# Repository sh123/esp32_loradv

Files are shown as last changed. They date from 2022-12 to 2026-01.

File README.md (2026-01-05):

# ESP32 Codec2/OPUS DV Handheld Transceiver

## Introduction
⚠ **Please note that this device is experimental and lacks any form of certification. The author holds no responsibility for any fines incurred due to spectrum misuse, legal violations, or damages caused during its use. As with any experimental project, it is essential that you fully understand what you are doing and use it at your own risk.**

This project is a hobby/amateur/toy/educational radio ESP32 based LoRa/FSK Codec2/OPUS DV 3d printed handheld trasceiver a.k.a. walkie-talkie, which is using 1W/2W `E22-400M30S/E22-400M33S` (SX1268) radio module (UHF, 70cm band) or optionally 100mW `RA-01/RA-02` (SX1278) module. 

In theory, it could also be used with other modules from `E22-xxxMxxS` series with compatible pinouts, but targetting other bands, such as `E22-868M30S/E22-900M30S` (SX1262) modules (UHF, 868/915 MHz) or `E22-170M33S`/`E22-220M30S`, but not tested.

It functions like a standard FM walkie-talkie and, for simplicity and traffic optimization, does not utilize any communication protocol. Instead, it transmits audio codec frames (DV) using pre-configured digital radio modulation, such as LoRA or FSK. There are ideas to add voice over AX.25 and perhaps M17 protocol support in the future.

Overall components cost for this project is about 15-20$.

Schematics for the new board design, which includes integrated components, can be found in the `extras/schematics` directory. The pinouts remain compatible with the first prototype version. While there is a designated space for a GPS module, it should not be soldered as it is not currently supported; it is included solely for potential future experiments.

First prototype is based on https://github.com/sh123/esp32_loraprs modem, but uses additional peripherals:
- I2S speaker module MAX98357A + 4-8ohm 3w speaker (40mm diameter)
- I2S microphone INMP441
- PTT button (new board uses right angeled push button)
- Rotary encoder with push button (new board uses EC11 right angeled encoder)
- Small OLED display SSD1306 128x32
- Battery voltage monitoring (just voltage divider fed into ADC pin, see schematics)
- Powered from a single commonly avaialble 18650 cell (for example from old laptop battery)
- Uses combined charge + 5v boost controller based on Hotchip HT4928S (it is usually used in low capacity single cell USB power banks), but **better to use controllers such as IP5305_SK or similar without auto shutdown on low current!**.

Supports next features:
- Supports LoRa and FSK (no FEC) modulation with configurable modulation parameters from settings
- Supports Codec2 (low bit rate, 700-3200 bps) and OPUS (medium/high bit rate, 2400-512000 bps) audio codecs, codec could be selected from settings
- Goes into ESP32 light sleep when no activity, so all power consumption is around 30-40mA when in sleep RX (even lower with built-in esp32 leds scrapped), wakes up on new data from radio module or when user starts transmitting, consumes about 90-100mA in active receive and about 700-800mA in full power 1W transmit, so single 18650 cell should last for about 48 hours when in idle RX
- Settings menu on long encoder button click, allows to change frequency and other parameters
- Output power tunable from settings from ~1mW (for ISM toy usage) up to 2W (for amateur radio experiments)
- Experimental no warranty privacy option for ISM low power usage (⚠ **check your country regulations if it is allowed by the ISM band plan before experimenting as it might be illegal in some countries**), it is based on [ChaCha20-Poly1305](https://en.wikipedia.org/wiki/ChaCha20-Poly1305) stream cypher provided by [rwheater/Crypto](https://github.com/rweather/arduinolibs) library, it is comparable to AES256, uses 256 bits key, provides message authentication, but should have lower CPU requirements and power usage.

Planned features/ideas:
- Frequency split repeater mode, where two transceivers will be linked using espnow, so one will receive voice on RX frequency and then send packet using espnow to second transmitter which will receive packet using espnow and re-transmit it on TX frequency, this way receiver and transmitter could be positioned further apart with separate antennas thus eliminating need for duplexer
- Bluetooth headset pairing to use with hands free, so can use headset instead of i2s speaker/mic when needed
- Voice over AX.25, so meta data such as callsign could be included and visible on the other end
- M17 protocol support

## Build instructions
- Modify `include/config.h` if needed
- Install platformio
- Build with platformio
- Upload with platformio

## BOM
Bill of materials (BOM) for the new board constuction (credits to n0p and his club members for collecting it)
```
ESP-WROOM32 30pin - https://es.aliexpress.com/item/1005005953505528.html
Modem LoRa E22-400M30S (SX1268) - https://es.aliexpress.com/item/1005003122961059.html
I2S speaker module MAX98357A - https://es.aliexpress.com/item/1005005383121121.html
4ohm 3w speaker (40mm diameter) - https://es.aliexpress.com/item/1005006684947554.html
I2S microphone INMP441 - https://es.aliexpress.com/item/1005007889064664.html
Rotary encoder with push button - https://es.aliexpress.com/item/1005008091948369.html 
Small OLED display SSD1306 128×32 - https://es.aliexpress.com/item/1005008096924594.html
Uses combined charge + 5v boost controller - https://es.aliexpress.com/item/1005008657948784.html

18650 Cell
Botón switch tactile SKHH angled - https://es.aliexpress.com/item/1005005369415986.html
SMA-J-P-X-ST-EM1 Edgemount - https://es.aliexpress.com/item/10000000835065.html
R1 - 100k 0603 - https://es.aliexpress.com/item/1005005677654015.html
R2-R7 - 10k 0603 - https://es.aliexpress.com/item/1005005677654015.html
C1, C3-C8, C10, C11 - 100nF 0603 - https://es.aliexpress.com/item/32371454429.html
C2 - Elec 100uF SMD 3×5,3 - https://es.aliexpress.com/item/1005006724593986.html
C9 - 47uF Radial D4 mm P2 mm - https://es.aliexpress.com/item/1005005022177024.html

GPS - OPTIONAL - UNSUPPORTED ON WALKIE FW - CONFLICTS WITH ON BOARD SERIAL PORT PROGRAMMER - https://es.aliexpress.com/item/1005008733474270.html
```

## Pictures

Two fully 3d printed prototypes were built based on `esp32_loraprs` modem board.

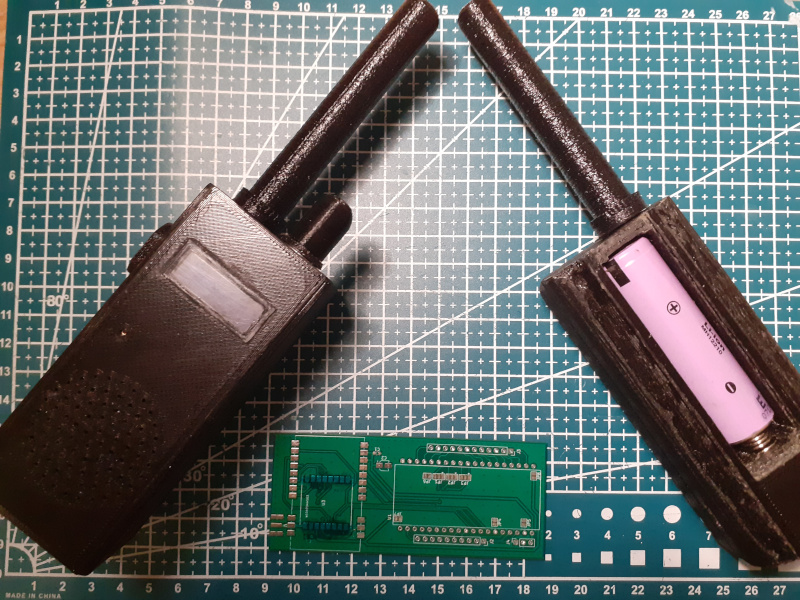
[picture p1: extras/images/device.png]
Device


List of peripherals used.

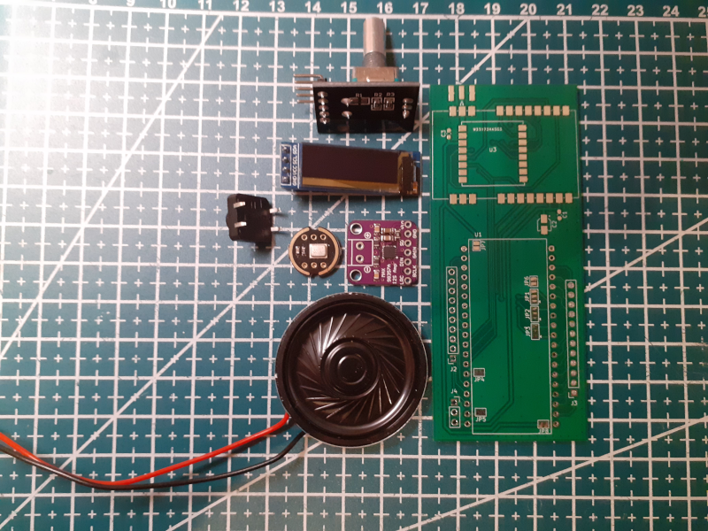
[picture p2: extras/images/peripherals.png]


New board design with all components integrated into the board (except battery and charging circuit).

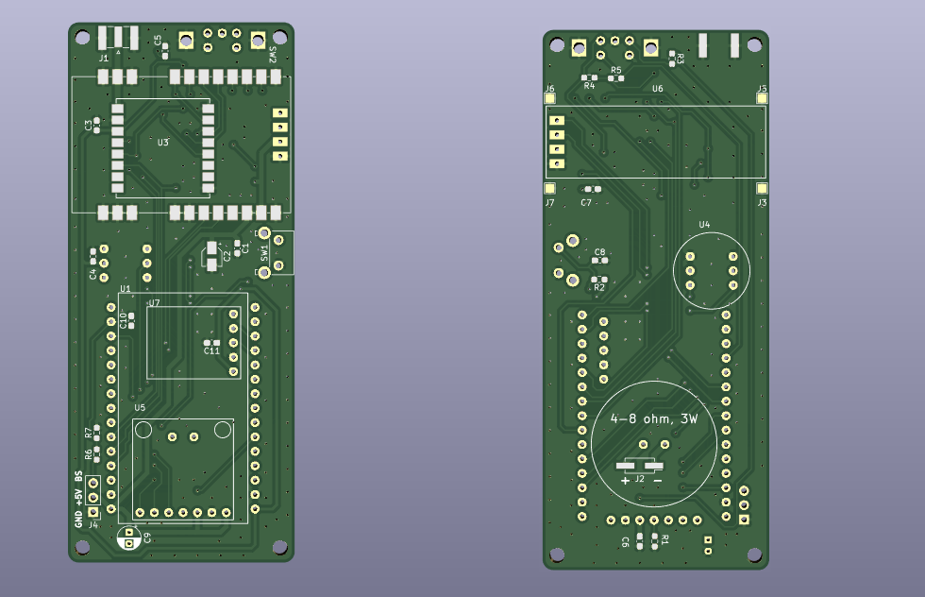
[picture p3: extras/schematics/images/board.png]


Case for the new board version with battery compartment.

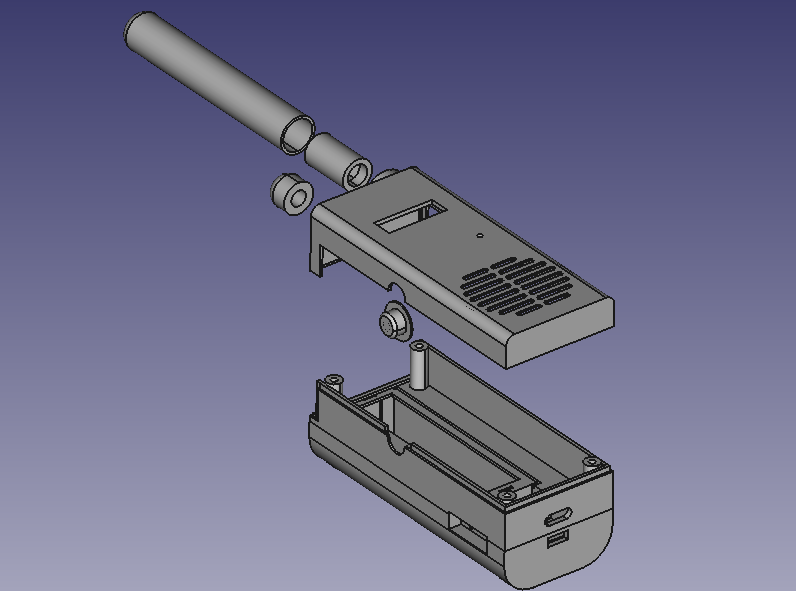
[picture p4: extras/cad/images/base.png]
CAD


Assembled board with new design.

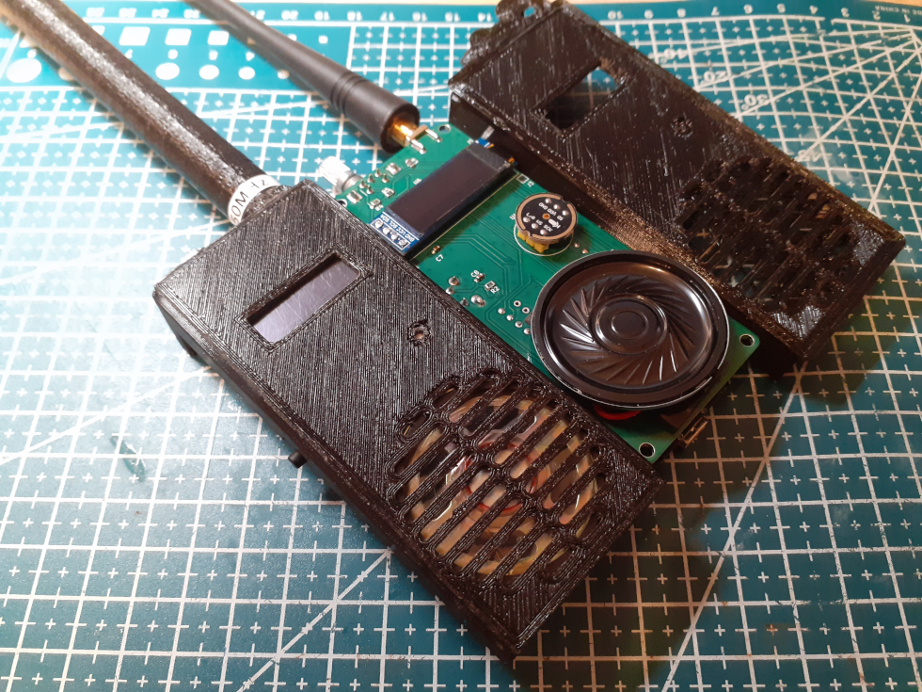
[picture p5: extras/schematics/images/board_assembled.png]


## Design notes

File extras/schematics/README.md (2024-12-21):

# ESP32 DV transceiver board

This is transceiver board for ESP32 DV handheld transceiver with integrated modules, except battery and charge controller.

Board

Board

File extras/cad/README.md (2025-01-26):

# CAD models for the transceiver case
- `antenna_base.*` - antenna foundation, antenna spiral widing is done with 1.3mm copper solid wire on 8mm diameter scaffolding, ~8 turns with 6mm step, with this configuration resonance will be at around 400 MHz, cut with small 2-4mm incriments to move resonance to higher frequency (e.g. to desired 433 or 446 MHz), control resonance after each step with antenna analyzer when antenna cover is attached.
- `antenna_cover_short.*` - antenna cover for 433 MHz (TPU plastic is preferred).
- `base.*` - model for the base part of the case where board is inserted.
- `upper.*` - upper part of the case with 18650 battery compartment and combined charge 5v boost up converter.
- `upper_no_battery.*` - upper part of the case without battery compartment, e.g. when planning to power using ESP32 USB port only.
- `knob.*` - rotary encoder knob (TPU plastic is preferred).
- `ptt.*` - PTT button cover (TPU plastic is preferred).
- `battery_lid.*` - battery compartment lid.

CAD

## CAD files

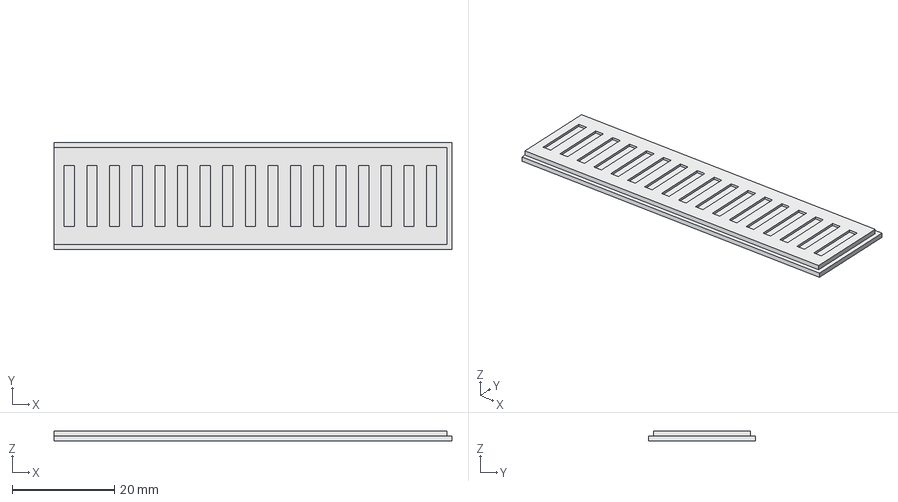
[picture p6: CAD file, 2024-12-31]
extras/cad/battery_lid.FCStd
78.0 x 21.0 x 2.00 mm

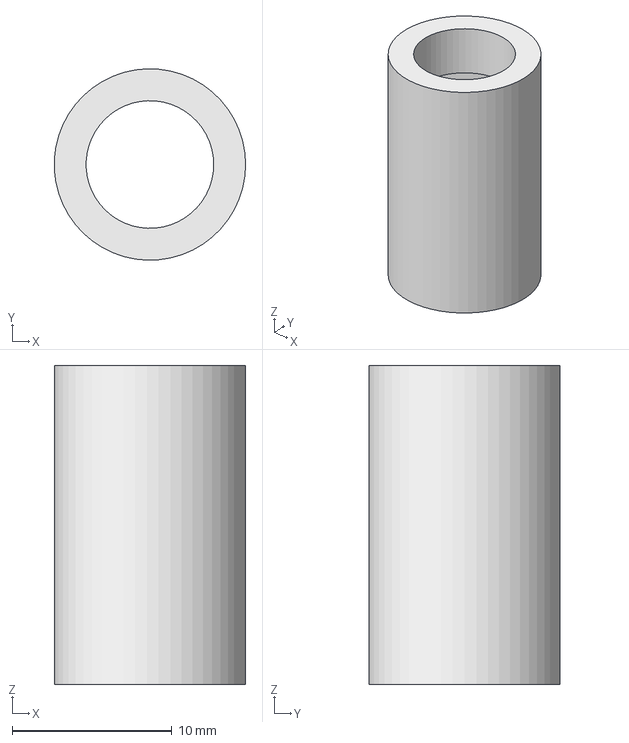
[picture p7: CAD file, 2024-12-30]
extras/cad/antenna_base.FCStd
12.0 x 12.0 x 20.0 mm

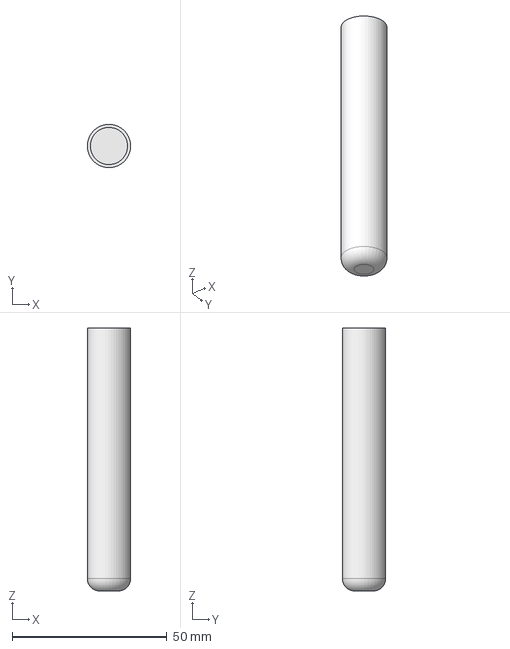
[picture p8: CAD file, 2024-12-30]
extras/cad/antenna_cover_short.FCStd
14.0 x 14.0 x 85.0 mm

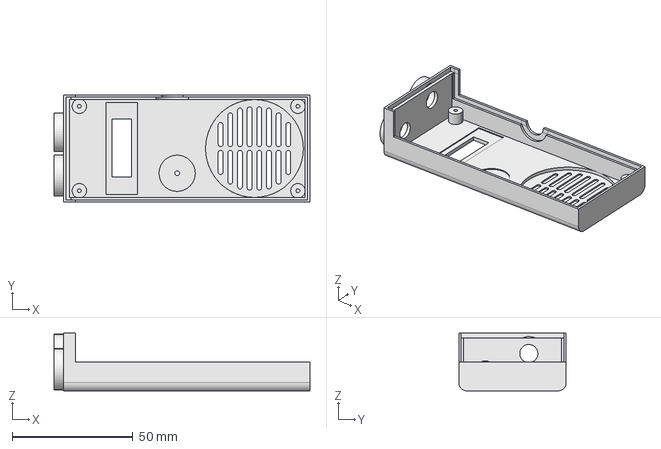
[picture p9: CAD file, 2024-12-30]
extras/cad/base.FCStd
106.0 x 44.5 x 24.0 mm

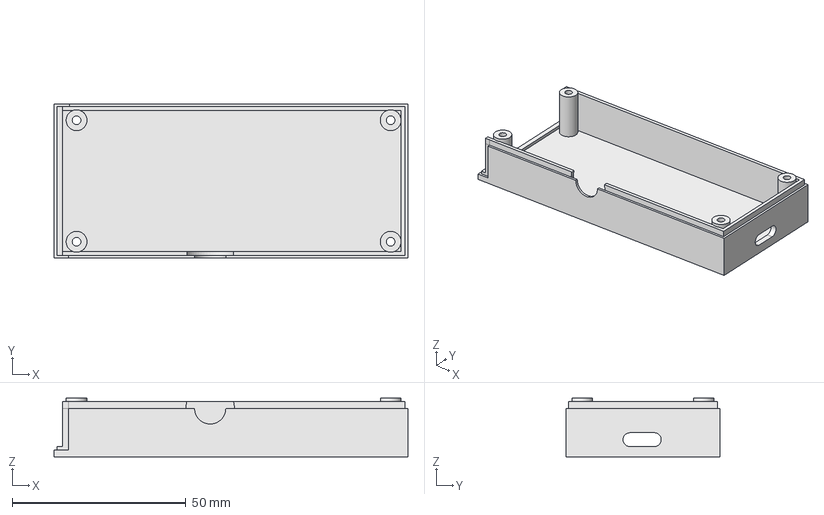
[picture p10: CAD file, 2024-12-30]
extras/cad/upper_no_battery.FCStd
102.0 x 44.5 x 17.0 mm

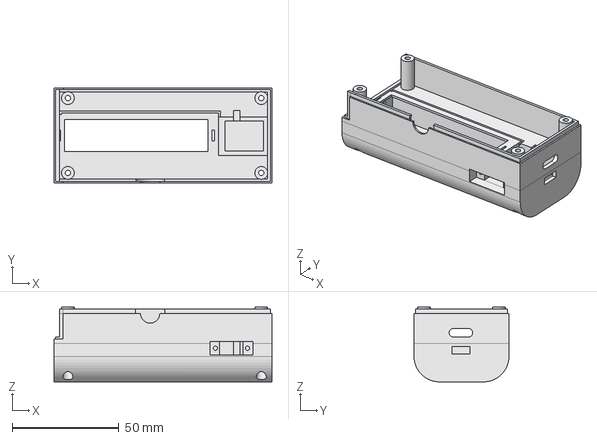
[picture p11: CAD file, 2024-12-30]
extras/cad/upper.FCStd
102.0 x 44.5 x 35.0 mm

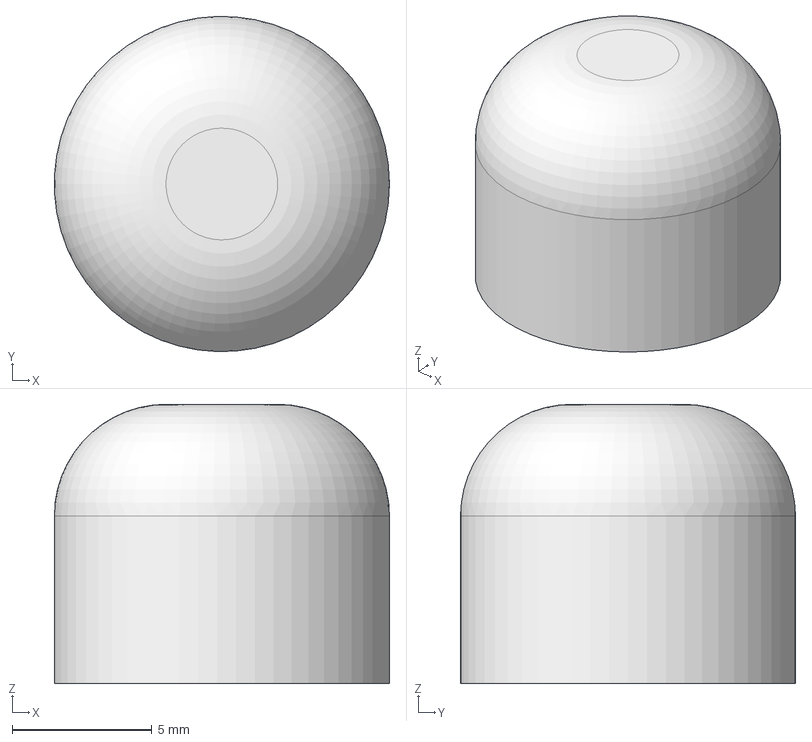
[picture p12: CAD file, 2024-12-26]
extras/cad/knob.FCStd
12.0 x 12.0 x 10.0 mm

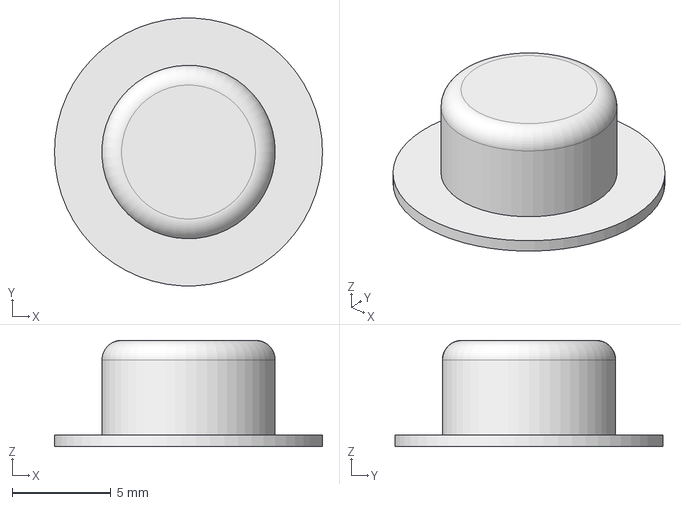
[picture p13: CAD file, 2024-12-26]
extras/cad/ptt.FCStd
13.6 x 13.6 x 5.40 mm

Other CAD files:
extras/cad/antenna_base.stl
extras/cad/antenna_cover_short.stl
extras/cad/base.stl
extras/cad/battery_lid.stl
extras/cad/knob.stl
extras/cad/ptt.stl
extras/cad/upper.stl
extras/cad/upper_no_battery.stl

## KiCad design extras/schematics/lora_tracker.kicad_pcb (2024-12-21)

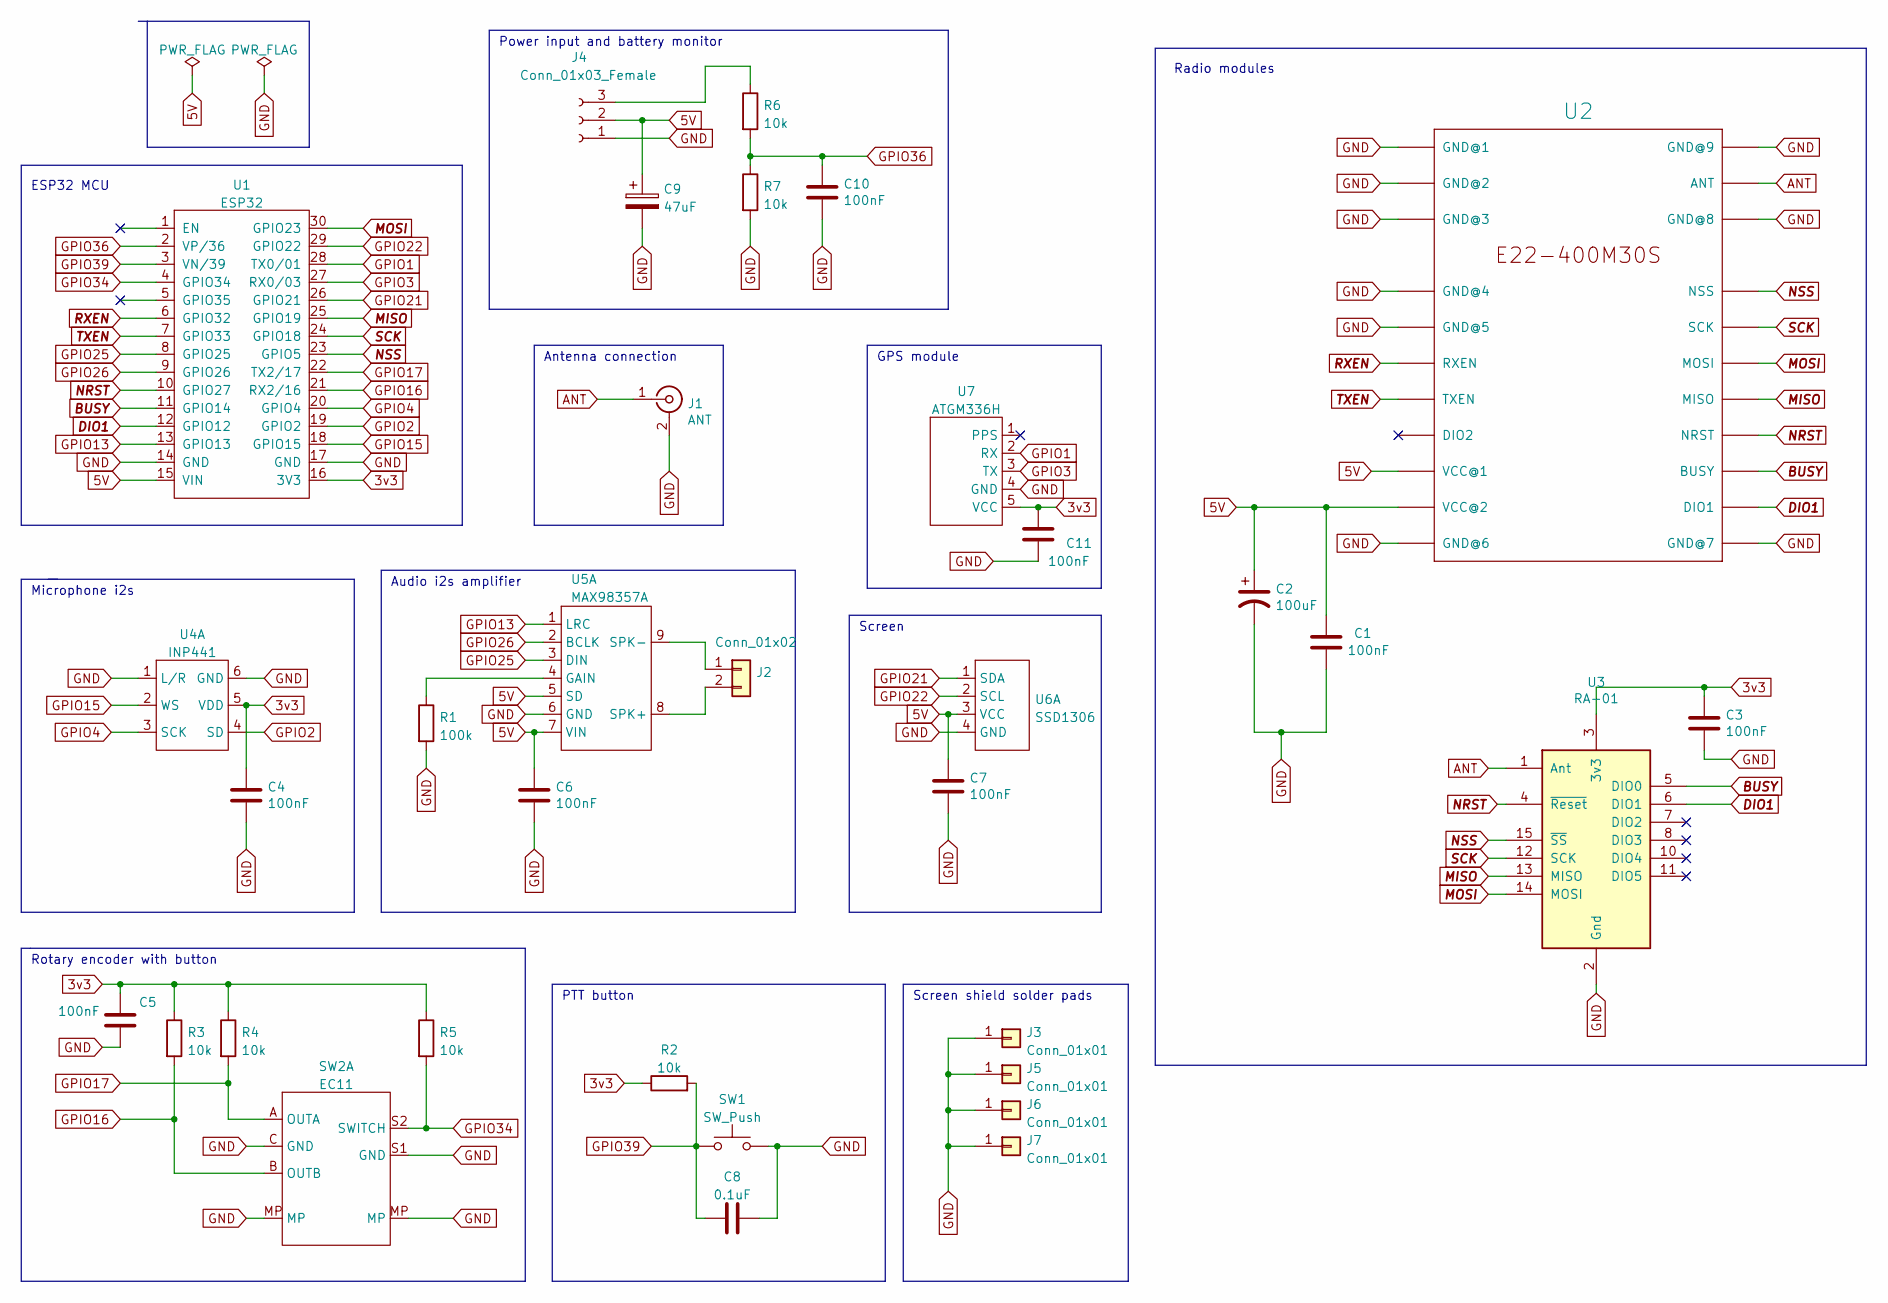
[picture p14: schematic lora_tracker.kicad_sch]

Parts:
C1, C3, C4, C5, C6, C7, C10, C11: 100nF; C_0603_1608Metric_Pad1.08x0.95mm_HandSolder
C2: 100uF; CP_Elec_3x5.3
C8: 0.1uF; C_0603_1608Metric_Pad1.08x0.95mm_HandSolder
C9: 47uF; CP_Radial_D4.0mm_P2.00mm
J1: ANT; SMA_Samtec_SMA-J-P-X-ST-EM1_EdgeMount
J2: Conn_01x02; PinHeader_2x01_P2.54mm_Vertical_SMD
J3, J5, J6, J7: Conn_01x01; TestPoint_Pad_1.5x1.5mm
J4: Conn_01x03_Female; PinHeader_1x03_P2.54mm_Vertical
R1: 100k; R_0603_1608Metric_Pad0.98x0.95mm_HandSolder
R2, R3, R4, R5, R6, R7: 10k; R_0603_1608Metric_Pad0.98x0.95mm_HandSolder
SW1: SW_Push; SW_Tactile_SKHH_Angled
SW2: EC11; ec11
U1: ESP32; esp32-devkit-wide_30pin
U2: E22-400M30S
U3: RA-01; Ai-Thinker-Ra-01-LoRa
U4: INP441; inp441
U5: MAX98357A
U6: SSD1306
U7: ATGM336H

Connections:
3v3: C3.1, C4.1, C5.1, C11.1, R2.1, R3.1, R4.1, R5.1, U1.16 (3V3), U3.3 (3v3), U4.5 (VDD), U7.5 (VCC)
5V: C1.1, C2.1, C6.1, C7.1, C9.1, J4.2, U1.15 (VIN), U2.9 (VCC@1), U2.10 (VCC@2), U5.5 (SD), U5.7 (VIN), U6.3 (VCC)
ANT: J1.1 (In), U2.21 (ANT), U3.1 (Ant)
BUSY: U1.11 (GPIO14), U2.14 (BUSY), U3.5 (DIO0)
DIO1: U1.12 (GPIO12), U2.13 (DIO1), U3.6 (DIO1)
GND: C1.2, C2.2, C3.2, C4.2, C5.2, C6.2, C7.2, C8.2, C9.2, C10.2, C11.2, J1.2 (Ext), J3.1, J4.1, J5.1, J6.1, J7.1, R1.2, R7.2, SW1.2, SW2.C (GND), SW2.MP, SW2.S1 (GND), U1.14 (GND), U1.17 (GND), U2.1 (GND@1), U2.2 (GND@2), U2.3 (GND@3), U2.4 (GND@4), U2.5 (GND@5), U2.11 (GND@6), U2.12 (GND@7), U2.20 (GND@8), U2.22 (GND@9), U3.2 (Gnd), U3.9 (Gnd), U3.16 (Gnd), U4.1 (L/R), U4.6 (GND), U5.6 (GND), U6.4 (GND), U7.4 (GND)
GPIO1: U1.28 (TX0/01), U7.2 (RX)
GPIO2: U1.19 (GPIO2), U4.4 (SD)
GPIO3: U1.27 (RX0/03), U7.3 (TX)
GPIO4: U1.20 (GPIO4), U4.3 (SCK)
GPIO13: U1.13 (GPIO13), U5.1 (LRC)
GPIO15: U1.18 (GPIO15), U4.2 (WS)
GPIO16: R3.2, SW2.B (OUTB), U1.21 (RX2/16)
GPIO17: R4.2, SW2.A (OUTA), U1.22 (TX2/17)
GPIO21: U1.26 (GPIO21), U6.1 (SDA)
GPIO22: U1.29 (GPIO22), U6.2 (SCL)
GPIO25: U1.8 (GPIO25), U5.3 (DIN)
GPIO26: U1.9 (GPIO26), U5.2 (BCLK)
GPIO34: R5.2, SW2.S2 (SWITCH), U1.4 (GPIO34)
GPIO36: C10.1, R6.2, R7.1, U1.2 (VP/36)
GPIO39: C8.1, R2.2, SW1.1, U1.3 (VN/39)
MISO: U1.25 (GPIO19), U2.16 (MISO), U3.13 (MISO)
MOSI: U1.30 (GPIO23), U2.17 (MOSI), U3.14 (MOSI)
NRST: U1.10 (GPIO27), U2.15 (NRST), U3.4 (~Reset)
NSS: U1.23 (GPIO5), U2.19 (NSS), U3.15 (~SS)
unnamed: J2.1, U5.9 (SPK-)
unnamed: J2.2, U5.8 (SPK+)
unnamed: J4.3, R6.1
unnamed: R1.1, U5.4 (GAIN)
RXEN: U1.6 (GPIO32), U2.6 (RXEN)
SCK: U1.24 (GPIO18), U2.18 (SCK), U3.12 (SCK)
TXEN: U1.7 (GPIO33), U2.7 (TXEN)

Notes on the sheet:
Antenna connection
Microphone i2s
Audio i2s amplifier
GPS module
Screen shield solder pads
Radio modules
PTT button
Power input and battery monitor
Screen
ESP32 MCU
Rotary encoder with button

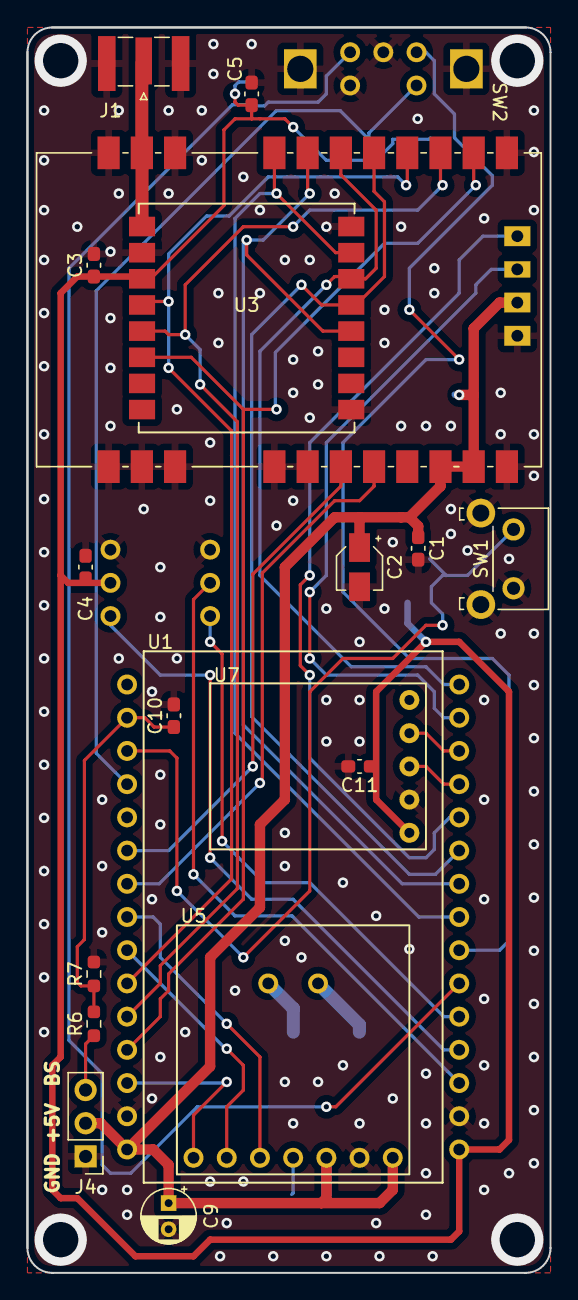
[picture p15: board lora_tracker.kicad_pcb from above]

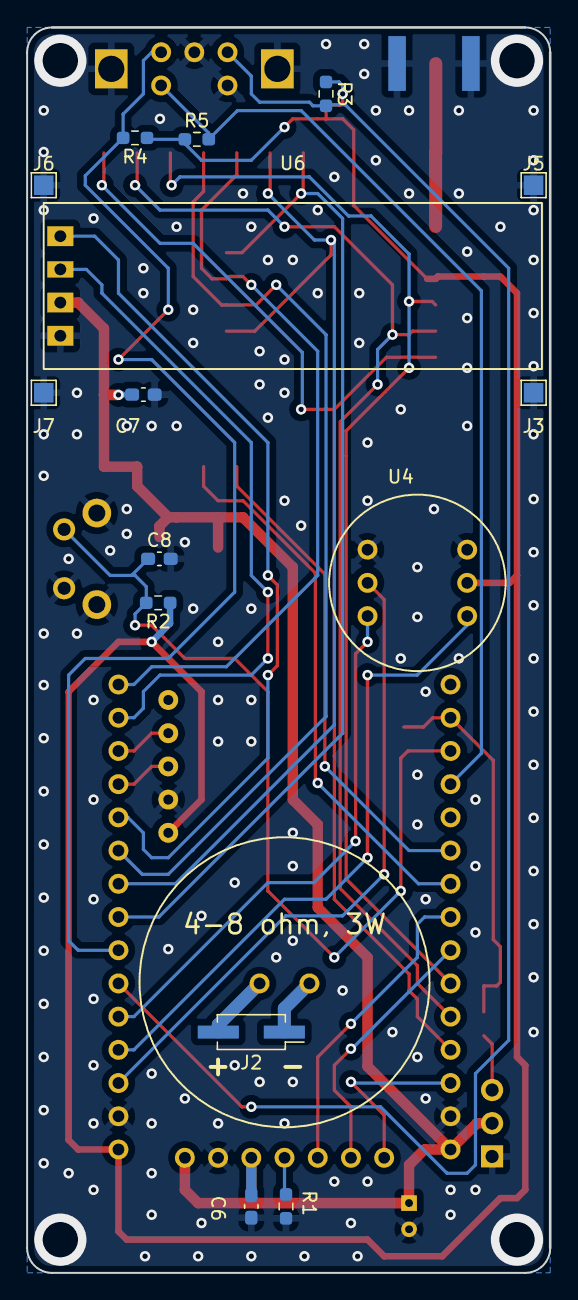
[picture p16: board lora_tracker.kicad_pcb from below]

Board: 2 copper layers, 40.0 x 95.2 mm, 34 parts (15 on the bottom side), 32 nets.

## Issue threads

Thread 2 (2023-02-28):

Comment out for SX127X module build error

jumbo5566, 2023-02-28:
Building in release mode
Compiling .pio\build\esp32dev\src\audio_task.cpp.o
Compiling .pio\build\esp32dev\src\hw_monitor.cpp.o
Compiling .pio\build\esp32dev\src\loradv_config.cpp.o
Compiling .pio\build\esp32dev\src\loradv_service.cpp.o
In file included from src/loradv_config.cpp:1:
include/loradv_config.h:14:48: note: #pragma message: Using default built-in config
 #pragma message("Using default built-in config")
                                                ^
In file included from include/loradv_config.h:15,
                 from src/loradv_config.cpp:1:
include/config.h:28:68: note: #pragma message: LoRa pin definitions are not found, redefining...
 #pragma message("LoRa pin definitions are not found, redefining...")
                                                                    ^
src/loradv_config.cpp: In member function 'void LoraDv::Config::InitializeDefault()':
include/config.h:42:37: error: 'RADIOLIB_NC' was not declared in this scope
 #define CFG_LORA_PIN_B              RADIOLIB_NC // (sx127x - dio1, sx126x/sx128x - busy)
                                     ^~~~~~~~~~~
src/loradv_config.cpp:36:15: note: in expansion of macro 'CFG_LORA_PIN_B'
   LoraPinB_ = CFG_LORA_PIN_B; // (sx127x - dio1, sx126x/sx128x - busy)
               ^~~~~~~~~~~~~~
*** [.pio\build\esp32dev\src\loradv_config.cpp.o] Error 1
In file included from include/hw_monitor.h:6,

jumbo5566, 2023-02-28:
i add loradv_config.h   #include <RadioLib.h> then OK

Closed 2023-03-01.

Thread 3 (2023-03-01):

i make a sch for loradv ,and i tested for heltec-v2.1

jumbo5566, 2023-03-01:
i make a sch for loradv ,and i tested for heltec-v2.1 board ,the default config tx mic ,rx spk sound is not big engouht,the sound quality is not good,but we can try more.

i nottice meshtastic module have codec2 sound tx rx function now.
it just use 4 gpio to work
I2S Word Select
The GPIO to use for the WS signal in the I2S interface.
I2S Data IN
The GPIO to use for the SD signal in the I2S interface.
I2S Data OUT
The GPIO to use for the DIN signal in the I2S interface.
I2S Clock
The GPIO to use for the SCK signal in the I2S interface.
https://meshtastic.org/docs/settings/moduleconfig/audio

sh123, 2023-03-01:
Encoder should change the volume when you rotate it clockwise, quality depends on the codec2 mode, 700 codec2 mode cannot have good sound quality in principle.

jumbo5566, 2023-03-02:
for Good loradv we can view this project:
https://m17project.org/get-started/software

jumbo5566, 2023-03-02:
https://github.com/nakhonthai/M17AnalogGateway
it is esp32 work wifi and Analog Codec2
i tested work good.
but it is only wifi walkie talkie.

sh123, 2023-03-03:
> for Good loradv we can view this project: https://m17project.org/get-started/software

not sure, it requires some effort to implement m17 protocol support

Closed 2023-04-13.

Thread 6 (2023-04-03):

question about specific use case - one way mic/audio transmission

B-nutze-RR, 2023-04-03:
HI, i played around with the lora/codec2 projects and really enjoy to learn from it ! I ask myself it's possible to use 868/915 Mhz lora like the sx1276 and ESP32 to realize a one way audio transmission . I look for a way to transmit on board audio from FPV drones that use a digital video transmission at 5.8Ghz and a 868 lora based control link - I don't look for perfect representation of the onboard audio situation but for a "low latency" representation of the prop noise - rpm and the pitch level of the noise onboard would already be helpful.
In general I want to use one firmware for the sending hardware and one for the receiving side - like ESP-c3 + I2c mic on one side and one with a headphone amp on the other side.

Would codec2 and 868 Mhz "one-way lora" be able to transmit the noise from a drone or is this type of sound chaos not working for that codec ?

Any idea how latency will behave with decreasing "link quality" in a constant one-way setup ?

THX !!

sh123, 2023-04-03:
@B-nutze-RR , I do not have any experience with drones, cannot help much, but sending noise over Codec2 does not make much sense, because it is adopted for speech, in other words, it "cuts" non-speech from the spectrum, which might be needed for your purposes.

B-nutze-RR, 2023-04-05:
@sh123 thanks for clarifying that - looks like missed that part on codec2.

It might have to work with telemetry data from the flight controller to emulate the "noise" i want. Things like motor RPM and certain PID values can work as audio indicator ( helpful for me personally).

Closed 2023-04-03.

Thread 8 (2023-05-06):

models of ESP32 development boards compatible with the project

Sergey19880206, 2023-05-06:
What esp32 board models were successfully used in the project? what boards are not recommended for use in the project?

R2AirVlad, 2023-05-06:
For using with included PCB version you need a "narrow" ESP32 wroom board like NodeMCU-32S 38P.

sh123, 2023-05-08:
From software point of view It could be any ESP32 esp32dev (per `platformio.ini`) board. I was using `ESP32 WROOM-32` and board mentioned in previous comment.

Closed 2023-05-08.

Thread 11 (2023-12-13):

Is it possible to add Opus for better quality audio?

happytm, 2023-12-13:
I know it will reduce range with higher data rate  Opus require but audio quality would be improved.

I am asking as you implemented Opus codec in your android app version. Can it be done for standalone implementation?

Thanks.

sh123, 2023-12-13:
That's good idea, I've published OPUS codec as Arduino library https://github.com/sh123/esp32_opus_arduino (also added Arduino libraries registry), loopback i2s example works OK for the first glance, will try to add it to this project.

happytm, 2023-12-13:
Thank you very much.

sh123, 2023-12-17:
Added OPUS, could be selected between Codec2/OPUS from settings, seems to work between two transceivers, but did not test very extensively.

Closed 2023-12-17.

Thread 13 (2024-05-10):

Connection diagram

uw5elk, 2024-05-10:
Hello.  Is there a diagram for connecting all the modules to the main board?

uw5elk, 2024-05-10:
In particular, to which pins to connect the display?

sh123, 2024-07-13:
@uw5elk, ssd1306 display library is using Wire module, which uses esp32 SCL (GPIO22) and SDA (GPIO21) pinouts.

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

uw5elk, 2024-07-13:
Дякую

Closed 2024-07-13.

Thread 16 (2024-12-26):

ESP32 module 30 pin - which one to use?

Radiomix2000, 2024-12-26:
The new PCB layout has halls to ESP32 module with 30 pins. Which one exactly should be used with the latest PCB version?

sh123, 2024-12-26:
I was using similar to this one, 30 pins, 25mm between left and right pinouts.

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

Closed 2024-12-26.

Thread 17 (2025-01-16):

New PCB ISP programming unsuccessful

Radiomix2000, 2025-01-16:
Tried to program ESP32 soldered to PCB with no success. Every time it terminated with status: "Failed to connect to ESP32: Download mode successfully detected, but getting no sync reply: The serial TX path seems to be down".
Programming ESP32 board outside PCB works good.
How to program ESP32, when it's already soldered to PCB?

sh123, 2025-01-16:
Never had this issue, it should work unless you soldered GPS module or your ESP32 pinouts are different.

Radiomix2000, 2025-01-16:
Yes? I  have GPS module soldered onto PCB. Then it could be the problem. Will try to sort it off.

sh123, 2025-01-16:
Do not solder it, sorry, I did not mention that, I just added place for GPS module for future experiments, so that I do not need to order new boards. There were no free pinouts anymore so I wired them to TX/RX, it should work, but programming and USB usage is not possible.

Closed 2025-01-16.

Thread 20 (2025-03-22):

Commercial product

happytm, 2025-03-22:
Few years late but commercial product based on your original idea:

https://lilygo.cc/products/t3-s3-mvsr
https://github.com/Xinyuan-LilyGO/T3-S3-MVSRBoard

Thanks.

R2AirVlad, 2025-03-22:
Yes! Actually they copied all idea and even naming from my GitHab project :)

https://github.com/R2AirVlad/LoRa_Voice_Demo_Project

sh123, 2025-03-22:
@happytm , that's nice as software is open source, but I personally not big fan of Lilygo horizontal boards layout for portable usage, but should be fine when standing on the table.

Closed 2025-03-22.

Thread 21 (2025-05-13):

Schematics

TobiasPSP, 2025-05-13:
Awesome project. I would like to build it without a custom pcb. Do you have a simple schematics image for breadboard build, or did I just overlook it?

Many thx for sharing your work!

sh123, 2025-05-14:
Hi, thank you. No, I do not have breadboard image, but there is Kicad schematics in https://github.com/sh123/esp32_loradv/tree/master/extras/schematics including gerber files, you can just order them from PCBWay or any other manufacturer, it will be just faster to construct it on the board than on the breadboard. There is one picture of breadboard construction at https://github.com/sh123/esp32_loradv/discussions/12

Closed 2025-05-14.

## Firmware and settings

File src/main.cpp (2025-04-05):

#include <Arduino.h>
#include <memory>

#include "service.h"

using namespace LoraDv;

static constexpr int LoopDelayMs = 10;

std::shared_ptr<Config> config_;
std::shared_ptr<Service> service_;

void setup() {
  Serial.begin(SERIAL_BAUD_RATE);
  while (!Serial);

  config_ = std::make_shared<Config>();
  config_->Load();
  
  service_ = std::make_shared<Service>(config_);
  service_->setup();
}

void loop() {
  service_->loop();
  delay(LoopDelayMs);
}

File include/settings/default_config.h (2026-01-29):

#ifndef DEFAULT_CONFIG_H
#define DEFAULT_CONFIG_H

#include <codec2.h>
#include <RadioLib.h>

#include "variant.h"

// saved settings version, increment to load new settings
#define CFG_VERSION                 10

// define in variant.h file if SX126X is in use
//#define USE_SX126X

// override in variant.h file, from https://github.com/jgromes/RadioLib/wiki/Modules
#ifndef MODULE_NAME
#define MODULE_NAME                 SX1268
#endif

#ifndef SERIAL_BAUD_RATE
#define SERIAL_BAUD_RATE            115200  // USB serial baud rate
#endif

// USB serial logging
// set to DebugLogLevel::LVL_TRACE for packet logging
// set to DebugLogLevel::LVL_NONE to disable logging
#ifndef CFG_LOG_LEVEL
#define CFG_LOG_LEVEL               DebugLogLevel::LVL_INFO
#endif

// modulation
#define CFG_MOD_TYPE_LORA           0   
#define CFG_MOD_TYPE_FSK            1
#ifndef CFG_MOD_TYPE
#define CFG_MOD_TYPE                CFG_MOD_TYPE_LORA         
#endif

// LoRa base pinouts
#ifndef CFG_LORA_PIN_NSS
#define CFG_LORA_PIN_NSS            5
#endif
#ifndef CFG_LORA_PIN_RST
#define CFG_LORA_PIN_RST            26
#endif
#ifndef CFG_LORA_PIN_DIO1
#define CFG_LORA_PIN_DIO1           12          // (sx127x - dio0, sx126x/sx128x - dio1)
#endif
#ifndef CFG_LORA_PIN_BUSY
#define CFG_LORA_PIN_BUSY           14          // (sx127x - dio1, sx126x/sx128x - busy)
#endif
#ifndef CFG_LORA_PIN_RXEN
#define CFG_LORA_PIN_RXEN           32          // (sx127x - unused, sx126x - RXEN pin number)
#endif
#ifndef CFG_LORA_PIN_TXEN
#define CFG_LORA_PIN_TXEN           33          // (sx127x - unused, sx126x - TXEN pin number)
#endif

// generic - frequencies, tune step, power
#ifndef CFG_LORA_FREQ_RX
#define CFG_LORA_FREQ_RX            433.775e6   // RX frequency in MHz
#endif
#ifndef CFG_LORA_FREQ_TX
#define CFG_LORA_FREQ_TX            433.775e6   // TX frequency in MHz
#endif
#ifndef CFG_LORA_FREQ_STEP
#define CFG_LORA_FREQ_STEP          25e3        // frquency step
#endif
#ifndef CFG_LORA_FREQ_MIN
#define CFG_LORA_FREQ_MIN           410e6       // minimum frequency
#endif
#ifndef CFG_LORA_FREQ_MAX
#define CFG_LORA_FREQ_MAX           493e6       // maximum frequency
#endif
#ifndef CFG_LORA_PWR
#define CFG_LORA_PWR                2           // output power in dBm (sx1268 with amplifier + 12 dbm)
#endif

// LoRa protocol default parameters (they need to match between devices!!!)
#ifndef CFG_LORA_BW
#define CFG_LORA_BW                 41.7e3      // discreate bandwidth (from 7.8 kHz up to 500 kHz)
#endif
#ifndef CFG_LORA_SF
#define CFG_LORA_SF                 7           // spreading factor (6 - 12), 6 requires implicit header mode
#endif
#ifndef CFG_LORA_CR
#define CFG_LORA_CR                 5           // coding rate (5 - 8)
#endif
#ifndef CFG_LORA_CRC
#define CFG_LORA_CRC                1           // 0 - disabled, 1 - 1 byte, 2 - 2 bytes
#endif
#ifndef CFG_LORA_SYNC
#define CFG_LORA_SYNC               0x12        // sync word (0x12 - private used by other trackers, 0x34 - public used by LoRaWAN)
#endif
#ifndef CFG_LORA_PREAMBLE_LEN
#define CFG_LORA_PREAMBLE_LEN       8           // preamble length from 6 to 65535
#endif

// fsk modem default parameters (they need to match between devices!!!)
#ifndef CFG_FSK_BIT_RATE
#define CFG_FSK_BIT_RATE            4.8         // bit rate in Kbps from 0.6 to 300.0
#endif
#ifndef CFG_FSK_FREQ_DEV
#define CFG_FSK_FREQ_DEV            1.2         // frequency deviation in kHz from 0.6 to 200.0
#endif
#ifndef CFG_FSK_RX_BW
#define CFG_FSK_RX_BW               9.7         // rx bandwidth in kHz discrete from 4.8 to 467.0
#endif
#ifndef CFG_FSK_SHAPING
#define CFG_FSK_SHAPING             RADIOLIB_SHAPING_NONE
#endif

// ptt button
#ifndef CFG_PTT_BTN_PIN
#define CFG_PTT_BTN_PIN             39          // pin for ptt button
#endif

// rotary encoder
#ifndef CFG_ENCODER_PIN_A
#define CFG_ENCODER_PIN_A           17
#endif
#ifndef CFG_ENCODER_PIN_B
#define CFG_ENCODER_PIN_B           16
#endif
#ifndef CFG_ENCODER_PIN_BTN
#define CFG_ENCODER_PIN_BTN         34
#endif
#ifndef CFG_ENCODER_PIN_VCC
#define CFG_ENCODER_PIN_VCC         -1
#endif
#ifndef CFG_ENCODER_STEPS
#define CFG_ENCODER_STEPS           4
#endif

// i2s speaker
#ifndef CFG_AUDIO_SPK_PIN_BCLK
#define CFG_AUDIO_SPK_PIN_BCLK      26
#endif
#ifndef CFG_AUDIO_SPK_PIN_LRC
#define CFG_AUDIO_SPK_PIN_LRC       13
#endif
#ifndef CFG_AUDIO_SPK_PIN_DIN
#define CFG_AUDIO_SPK_PIN_DIN       25
#endif

// i2s mic
#ifndef CFG_AUDIO_MIC_PIN_SD
#define CFG_AUDIO_MIC_PIN_SD        2
#endif
#ifndef CFG_AUDIO_MIC_PIN_WS
#define CFG_AUDIO_MIC_PIN_WS        15
#endif
#ifndef CFG_AUDIO_MIC_PIN_SCK
#define CFG_AUDIO_MIC_PIN_SCK       4
#endif

// battery monitor
#ifndef CFG_AUDIO_BATTERY_MON_PIN
#define CFG_AUDIO_BATTERY_MON_PIN   36
#endif
#ifndef CFG_AUDIO_BATTERY_MON_CAL
#define CFG_AUDIO_BATTERY_MON_CAL   0.25f
#endif
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

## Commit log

2024-10-29 Update circular buffer, SSD1306 and encoder libraries
2024-10-29 Redesign volume and add AGC for playback
    [loradv_config.cpp, loradv_service.cpp]
2024-10-30 Added schematics
    [lora_tracker-B.Cu.gbl, lora_tracker-B.Mask.gbs, lora_tracker-B.SilkS.gbo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]
2024-10-30 Migrated libraries to kicad_sym
2024-10-30 Add missing files
    [lora_tracker.kicad_sch]
2024-10-30 Updated esp32 symbol
2024-10-30 Update schematics
    [lora_tracker.kicad_sch]
2024-10-31 Updated schematics
    [lora_tracker.kicad_pcb, lora_tracker.kicad_sch]
2024-11-16 Added gerber
    [lora_tracker-B_Cu.gbl, lora_tracker-B_Mask.gbs, lora_tracker-B_Silkscreen.gbo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]
2024-11-16 Removed old files
    [lora_tracker-B.Cu.gbl, lora_tracker-B.Mask.gbs, lora_tracker-B.SilkS.gbo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]
2024-11-16 Added gerber files
    [lora_tracker-B_Cu.gbl, lora_tracker-B_Mask.gbs, lora_tracker-B_Silkscreen.gbo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]
2024-12-23 Added empty models
    [base.FCStd, battery_lid.FCStd, knob.FCStd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]
2024-12-24 Update base model
    [base.FCStd]
2024-12-24 Update model
    [base.FCStd]
2024-12-24 Update main model
    [base.FCStd, base.stl]
2024-12-26 Update models
    [base.FCStd, ptt.FCStd, ptt.stl]
2024-12-26 Added knob
    [knob.FCStd, knob.stl]
2024-12-29 Updated battery compartment model
    [base.FCStd, upper.FCStd, upper.stl]
2024-12-30 Added upper cover with no battery compartment
    [upper_no_battery.FCStd, upper_no_battery.stl]
2024-12-30 Update image
    [base.FCStd]
2024-12-30 Added antenna models
    [antenna_base.FCStd, antenna_base.stl, antenna_cover_short.FCStd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]
2024-12-31 Battery lid
    [battery_lid.FCStd, battery_lid.stl]
2025-01-02 Pin audio and radio tasks to separate cores
2025-04-28 Add de-allocation of one of buffers
2025-05-01 Change trace level
2025-12-18 Update libraries and fix issue with receiving
    [default_config.h, service.cpp]
2025-12-19 Change default parameters and set HPF fitler frequency to 300 Hz
2025-12-24 Fix typo in README regarding battery life
2026-01-04 Power management optiizations
2026-01-04 Revise power controller recommendation in README
    Updated information about the power controller recommendation.
2026-01-28 Do not make power management optimizations, add separate platformio target for that
